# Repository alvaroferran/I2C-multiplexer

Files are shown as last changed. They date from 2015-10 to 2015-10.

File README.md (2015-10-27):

# I2C Multiplexer
#### PCA9548 i2c multiplexer board and library

&nbsp;
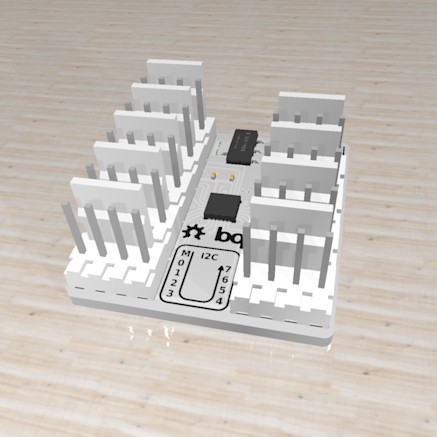
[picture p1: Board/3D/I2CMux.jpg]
board


This repository contains the multiplexer board and  an arduino library. 

This module is useful when multiple i2c devices must be connected to a microcontroller but share fixed addresses, for example using several identical sensors with the same hardware-defined address. To solve this connect each offending sensor to different i2c buses and simply select the appropiate channel before communicating with the device as usual.

#### BOARD

·The board has one input i2c channel and eight output ones. The input works at 5V level while the rest work at 3.3V.
&nbsp;
·It has eight possible, hardware-defined I2C addresses, which are selectable through three solder pads, as in the following table:

| A2 | A1 | A0 | I2C Address |
| :---: | :---: | :---: | :---: |
| 0  | 0  | 0  | 0X70 |
| 0  | 0  | 1  | 0X71 |
| 0  | 1  | 0  | 0X72 |
| 0  | 1  | 1  | 0X73 |
| 1  | 0  | 0  | 0X74 |
| 1  | 0  | 1  | 0X75 |
| 1  | 1  | 0  | 0X76 |
| 1  | 1  | 1  | 0X77 |

&nbsp;
·The pads on next to each connector enables that bus' 4.7k pullup resistors. These pads should be soldered if there were no other pullup resistors on the bus.
&nbsp;

#### LIBRARY

· To install the library simply copy the folder "I2CMux" into your folder "sketchbook/libraries/".

&nbsp;

· The module's address is passed to the constructor, while the channel is selected by the method "switchToBus(busNumber)", with busNumber between 0 and 7.

&nbsp;

· In the "examples" subfolder an example sketch is available which demonstrates how to switch between different i2c channels, reading data from two [BNO055](https://github.com/bqlabs/BNO055) sensors with the same address in different buses.

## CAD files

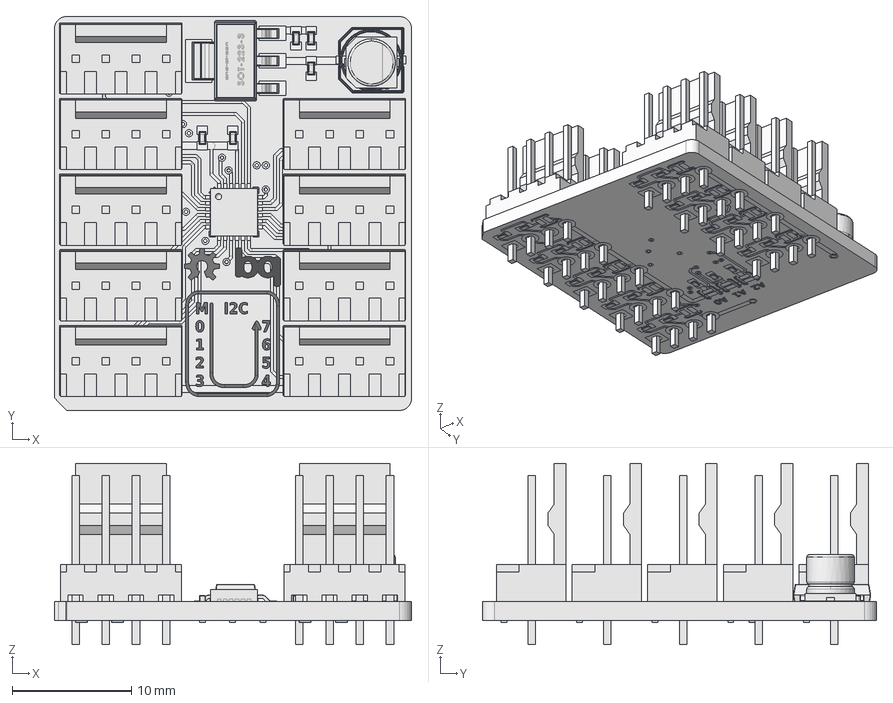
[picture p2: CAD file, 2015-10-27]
Board/3D/I2CMux.fcstd
30.0 x 33.1 x 15.2 mm
Board
C4
C2
C3
C1
C5
C6
IC1
IC2
R1
R6
R2
R7
R11
R15
R3
R8
R12
R16
R4
R9
R13
R17
R5
R10
R14
R18
R19
R20
R21
JP2
JP3
JP4
JP5
JP6
JP7
JP8
JP9
JP1
Top_1
Bottom_16
tPad_17
bPad_18
tPlace_21
bPlace_22
tDocu_51
bDocu_52
ShapeString
ShapeString001
ShapeString002
ShapeString003
ShapeString004
ShapeString005
ShapeString006
ShapeString007
ShapeString008
ShapeString009
ShapeString010
ShapeString011
ShapeString012

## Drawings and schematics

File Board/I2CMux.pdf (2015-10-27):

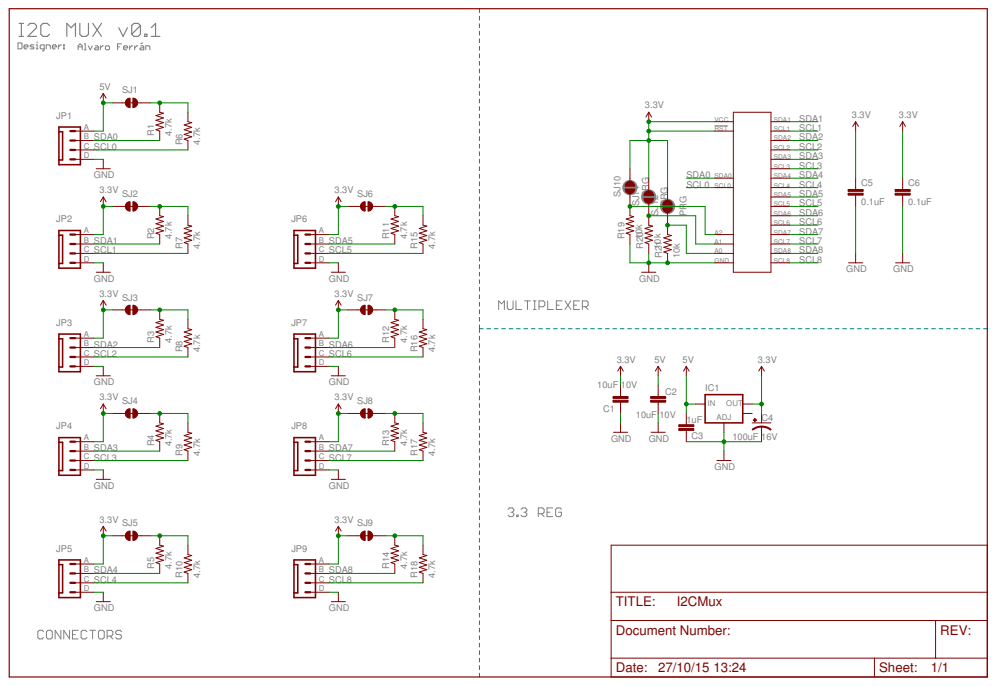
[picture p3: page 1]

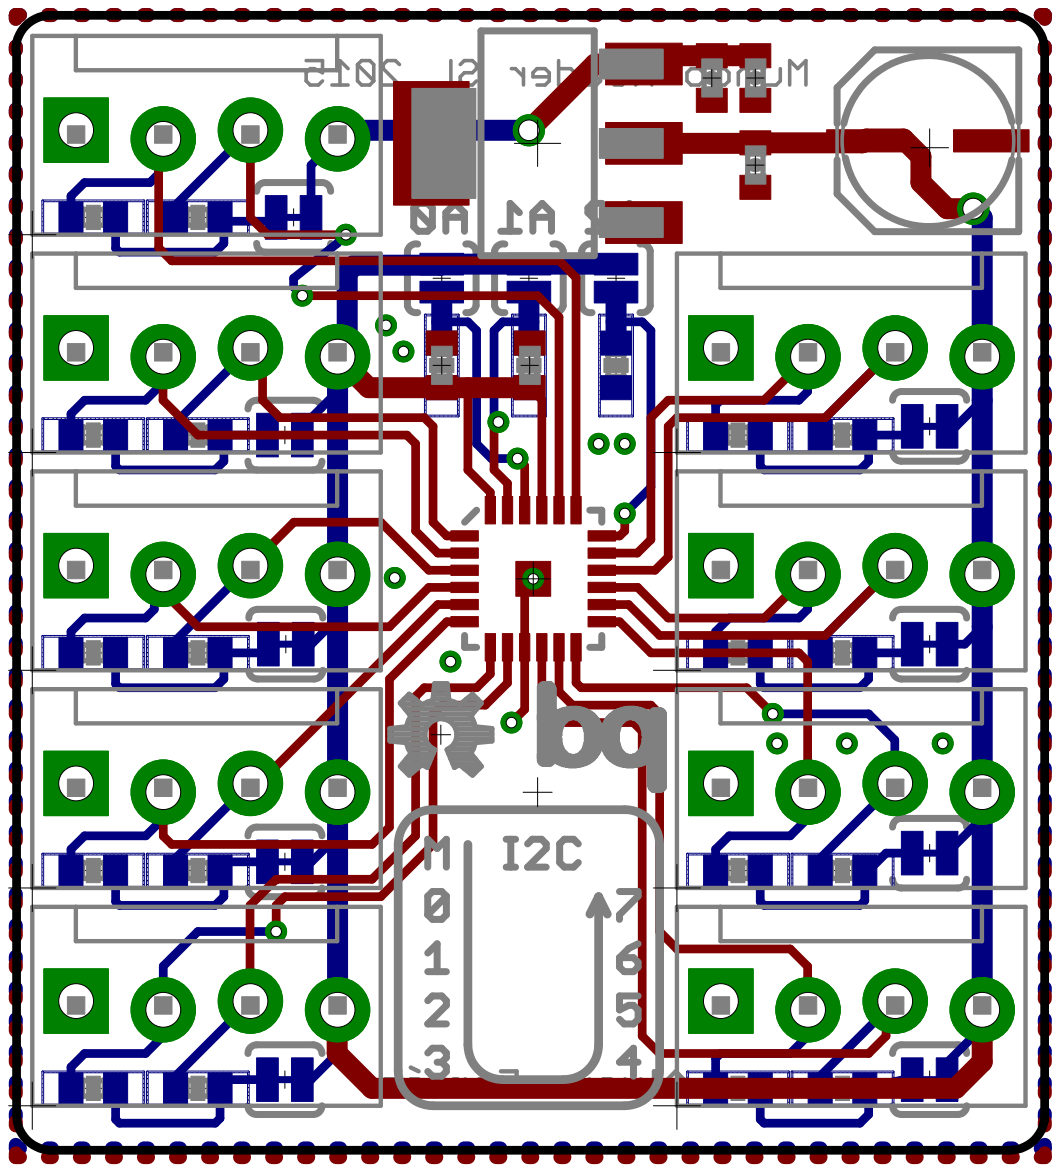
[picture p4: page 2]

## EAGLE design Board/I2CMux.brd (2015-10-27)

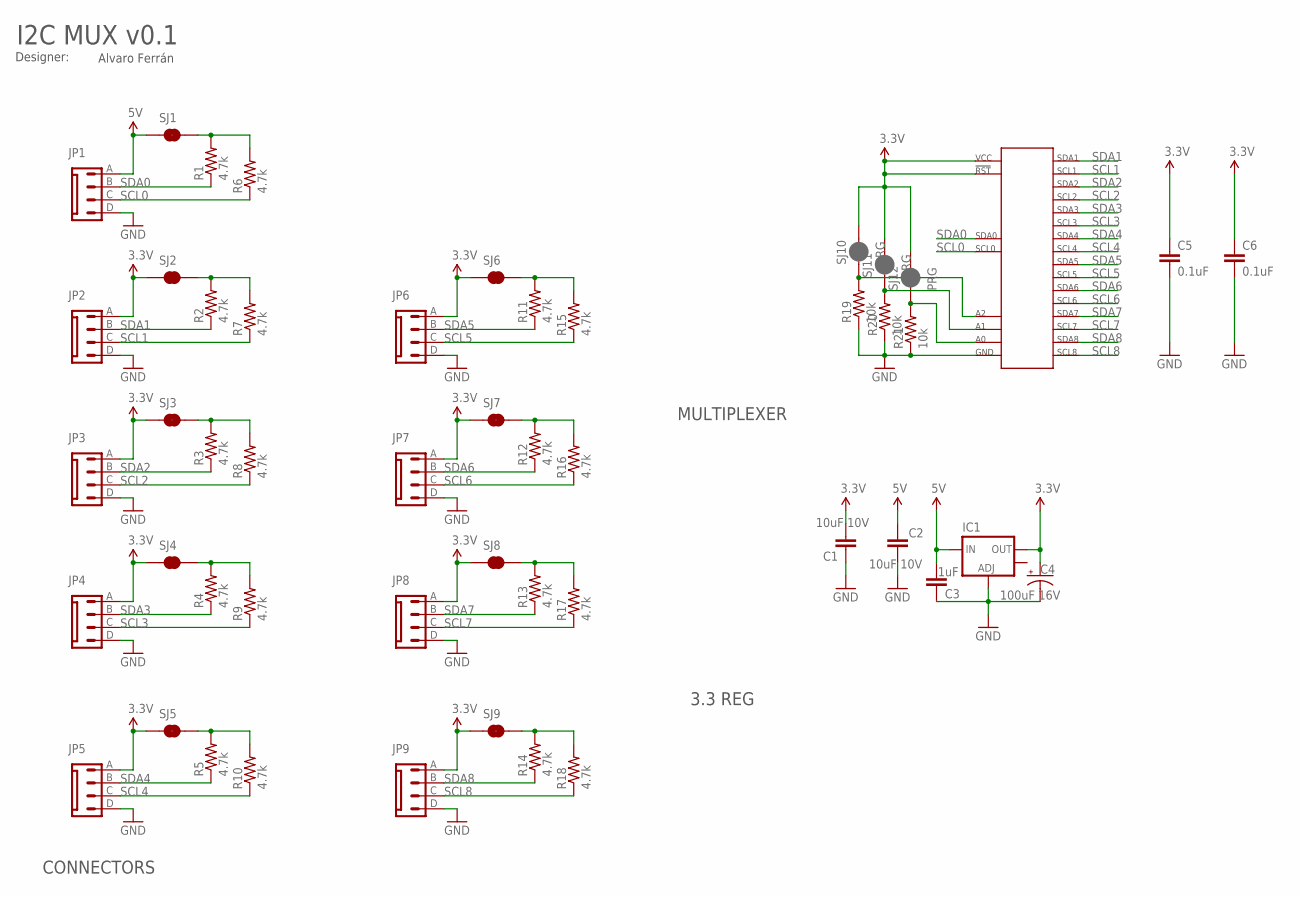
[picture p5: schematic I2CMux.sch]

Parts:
C1, C2: 10uF 10V; 0402-CAP
C3: 1uF; 0402-CAP
C4: 100uF 16V; PANASONIC_C
C5, C6: 0.1uF; 0402-CAP
IC1: V_REG_LM1117SOT223; SOT223
IC2: PCA9548A; PCA9548ABS
JP1, JP2, JP3, JP4, JP5, JP6, JP7, JP8, JP9: MX-6410-04A
R1, R2, R3, R4, R5, R6, R7, R8, R9, R10, R11, R12, R13, R14, R15, R16, R17, R18: 4.7k; 0402-RES
R19, R20, R21: 10k; 0402-RES
SJ1, SJ2, SJ3, SJ4, SJ5, SJ6, SJ7, SJ8, SJ9: JUMPER-PAD-2-NC_BY_TRACE; PAD-JUMPER-2-NC_BY_TRACE_YES_SILK
SJ10, SJ11, SJ12: PRG; PAD-JUMPER-2-NC_BY_PASTE_YES_SILK

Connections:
3.3V: C1.2, C4.+, C5.1, C6.1, IC1.2 (OUT), IC2.21 (VCC), IC2.24 (!RESET), JP2.A, JP3.A, JP4.A, JP5.A, JP6.A, JP7.A, JP8.A, JP9.A, SJ2.1, SJ3.1, SJ4.1, SJ5.1, SJ6.1, SJ7.1, SJ8.1, SJ9.1, SJ10.2, SJ11.2, SJ12.2
5V: C2.2, C3.2, IC1.3 (IN), JP1.A, SJ1.1
A0: IC2.22 (A0), R21.2, SJ12.1
A1: IC2.23 (A1), R20.2, SJ11.1
A2: IC2.18 (A2), R19.2, SJ10.1
GND: C1.1, C2.1, C3.1, C4.-, C5.2, C6.2, IC1.1 (ADJ), IC2.9 (GND), IC2.THERMAL (GND), JP1.D, JP2.D, JP3.D, JP4.D, JP5.D, JP6.D, JP7.D, JP8.D, JP9.D, R19.1, R20.1, R21.1
unnamed: R1.2, R6.2, SJ1.2
unnamed: R2.2, R7.2, SJ2.2
unnamed: R3.2, R8.2, SJ3.2
unnamed: R4.2, R9.2, SJ4.2
unnamed: R5.2, R10.2, SJ5.2
unnamed: R14.2, R18.2, SJ9.2
unnamed: R13.2, R17.2, SJ8.2
unnamed: R12.2, R16.2, SJ7.2
unnamed: R11.2, R15.2, SJ6.2
SCL0: IC2.19 (SCL0), JP1.C, R6.1
SCL1: IC2.2 (SCL1), JP2.C, R7.1
SCL2: IC2.4 (SCL2), JP3.C, R8.1
SCL3: IC2.6 (SCL3), JP4.C, R9.1
SCL4: IC2.8 (SCL4), JP5.C, R10.1
SCL5: IC2.11 (SCL5), JP6.C, R15.1
SCL6: IC2.13 (SCL6), JP7.C, R16.1
SCL7: IC2.15 (SCL7), JP8.C, R17.1
SCL8: IC2.17 (SCL8), JP9.C, R18.1
SDA0: IC2.20 (SDA0), JP1.B, R1.1
SDA1: IC2.1 (SDA1), JP2.B, R2.1
SDA2: IC2.3 (SDA2), JP3.B, R3.1
SDA3: IC2.5 (SDA3), JP4.B, R4.1
SDA4: IC2.7 (SDA4), JP5.B, R5.1
SDA5: IC2.10 (SDA5), JP6.B, R11.1
SDA6: IC2.12 (SDA6), JP7.B, R12.1
SDA7: IC2.14 (SDA7), JP8.B, R13.1
SDA8: IC2.16 (SDA8), JP9.B, R14.1

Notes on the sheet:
I2C MUX v0.1
Designer:
Alvaro Ferrán
MULTIPLEXER
3.3 REG
CONNECTORS

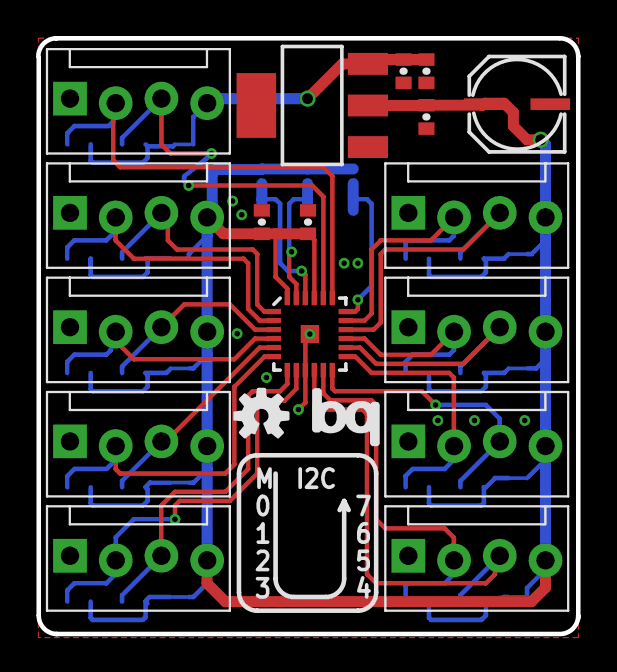
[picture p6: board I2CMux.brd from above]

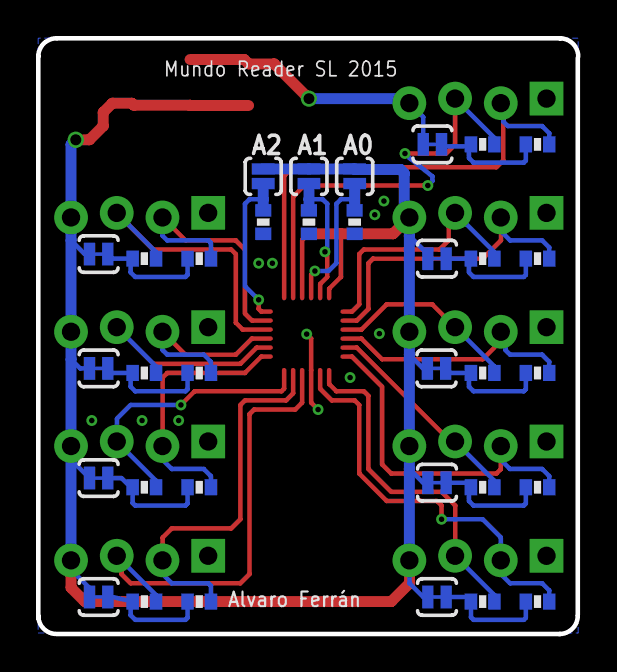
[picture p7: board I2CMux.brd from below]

Board: 2 copper layers, 30.0 x 33.1 mm, 52 parts (33 on the bottom side), 33 nets.

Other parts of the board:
LOGO3: OSHW-LOGOS; OSHW-LOGO-S
U$2: BQ_LOGO_MEDIUM

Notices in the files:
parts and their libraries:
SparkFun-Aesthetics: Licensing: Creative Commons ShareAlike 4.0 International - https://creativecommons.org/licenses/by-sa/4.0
